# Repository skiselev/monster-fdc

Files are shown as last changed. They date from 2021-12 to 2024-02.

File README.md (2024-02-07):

# Monster Floppy Disk Controller (Monster FDC)
ISA floppy disk controller card that supports up to 8 floppy drives

## Introduction
Monster FDC is an ISA floppy disk controller card that features two FDCs. Each FDC supports up to four floppy drives. IRQ and DMA channel are configurable for the secondary FDC, and they are hardwired to IRQ6 and DMA2 for the primary FDC. The card also includes a serial port (UART) with configurable I/O address and IRQ.

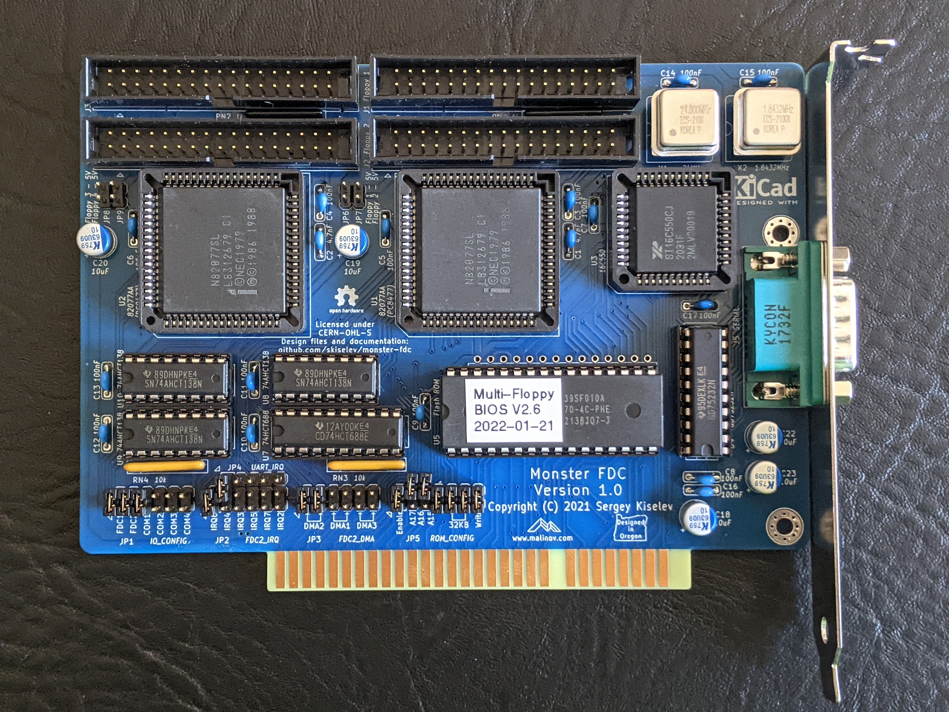
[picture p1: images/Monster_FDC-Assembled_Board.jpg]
Monster FDC Assembled Board
 

## User Manuals

* Refer to [Assembly Instructions](Assembly_Instructions.md) for the controller board building instructions
* Refer to [User Manual](User_Manual.md) for configuration, installation, and using the controller board in the computer

## Hardware Documentation

### Schematic and PCB Layout

[Schematic - Version 1.0](KiCad/isa_monster_fdc-Schematic-1.0.pdf)

[PCB Layout - Version 1.0](KiCad/isa_monster_fdc-Board-1.0.pdf)

### Bill of Materials

#### Version 1.0

[Monster FDC project on Mouser.com](https://www.mouser.com/ProjectManager/ProjectDetail.aspx?AccessID=8ae2858f5a) - View and order all components except of the PCB and the FDC ICs. Note that this BOM includes multiple alternatives for some parts (for example, for 2x17 pin floppy disk connector). Make sure to refer to the BOM below to order the right number of components.

Monster FDC project on Tindie: [Complete Board](https://www.tindie.com/products/weird/monster-fdc/); [Monster FDC PCB](https://www.tindie.com/products/weird/monster-fdc-pcb-only/).

Component type     | Reference | Description                                 | Quantity | Possible sources and notes 
------------------ | --------- | ------------------------------------------- | -------- | --------------------------
PCB                |           | Monster PCB - Version 1.0                   | 1        | Buy from my Tindie store: [Monster FDC PCB](https://www.tindie.com/products/weird/monster-fdc-pcb-only/), or order from a PCB manufacturer of your choice using provided Gerber or KiCad files. It is recommended to use hard gold plating on the card edge connector. ENIG finish might work, but it is not as reliable. Definitely **DO NOT** use HASL finish on card edge connector.
Integrated Circuit | U1, U2    | Intel 82077AA FDC, 68 pin PLCC              | 2        | eBay; Possible replacements: National Semiconductor PC8477BV-1 or PC8477AV-1, Intel 82077SL, Intel 82077AA with various suffixes
Integrated Circuit | U3        | 16C550 UART, 44 pin PLCC                    | 1        | Mouser [701-ST16C550CJ44-F](https://www.mouser.com/ProductDetail/701-ST16C550CJ44-F)
Integrated Circuit | U4        | GD75232N RS-232 Transceivers, 20 pin DIP    | 1        | Mouser [595-GD75232N](https://www.mouser.com/ProductDetail/595-GD75232N)
Integrated Circuit | U5        | SST39SF010A - 128 KiB Flash ROM, 32 pin DIP | 1*       | Mouser [804-39SF010A7CPHE](https://www.mouser.com/ProductDetail/804-39SF010A7CPHE); Possible replacements: 128 KiB, 256 KiB, or 512 KiB 5V only Flash ROMs from other vendors. Note: Install either U5 or U6. It is recommended to install U5
Integrated Circuit | U6        | 28C256 32 KiB or 28C64 8 KiB EEPROM, 28 pin DIP | 1*   | Mouser [556-AT28C25615PU](https://www.mouser.com/ProductDetail/556-AT28C25615PU), [556-AT28C64B15PU](https://www.mouser.com/ProductDetail/556-AT28C64B15PU). Note: Install either U5 or U6. It is recommended to install U5
Integrated Circuit | U7        | CD74HCT688E Magnitude Comparator, 20 pin DIP | 1       | Mouser [595-CD74HCT688E](https://www.mouser.com/ProductDetail/595-CD74HCT688E)
Integrated Circuit | U8 - U10  | SN74AHCT138N 3-to-8 Decoder, 16 pin DIP     | 3        | Mouser [595-SN74AHCT138N](https://www.mouser.com/ProductDetail/595-SN74AHCT138N)
Crystal Oscillator | X1        | 24 MHz, 4 pin DIP, Half Can                 | 1        | Mouser [520-TCH2400](https://www.mouser.com/ProductDetail/520-TCH2400)
Crystal Oscillator | X2        | 1.8432 MHz, 4 pin DIP, Half Can             | 1        | Mouser [520-TCH184-X](https://www.mouser.com/ProductDetail/520-TCH184-X)
Connector          | J1 - J4   | 2x17 pin shrouded header, 2.54 mm pitch, vertical | 4  | Mouser [517-30334-6002](https://www.mouser.com/ProductDetail/517-30334-6002)
Connector          | J5        | DE-9 D-Sub connector, male, right angle     | 1        | Mouser [806-K22X-E9P-N-99](https://www.mouser.com/ProductDetail/806-K22X-E9P-N-99)
Pin Header         | JP1 - JP3 | 2x6 pin header, 2.54 mm pitch, vertical     | 3        | Mouser [649-67996-112HLF](https://www.mouser.com/ProductDetail/649-67996-112HLF)
Pin Header         | JP4       | 1x5 pin header, 2.54 mm pitch, vertical     | 1        | Mouser [649-68000-205HLF](https://www.mouser.com/ProductDetail/649-68000-205HLF)
Pin Header         | JP5       | 2x7 pin header, 2.54 mm pitch, vertical     | 1        | Mouser [649-67996-114HLF](https://www.mouser.com/ProductDetail/649-67996-114HLF)
Pin Header         | JP6 - JP9 | 2x2 pin header, 2.54 mm pitch, vertical     | 2*       | Mouser [649-67996-104HLF](https://www.mouser.com/ProductDetail/649-67996-104HLF). Note: Do not install unless using PS/2 floppy drives that are powered by pin 3
Capacitor          | C1, C2    | 4.7 nF, 50V, MLCC, 5 mm pitch               | 2*       | Mouser [810-FG28X7R1H472KNT0](https://www.mouser.com/ProductDetail/810-FG28X7R1H472KNT0). Note: Optional, only required when using Intel 82077AA FDC
Capacitor          | C3 - C17  | 100 nF, 50V, MLCC, 5 mm pitch               | 15       | Mouser [810-FG28X7R1H104KNT6](https://www.mouser.com/ProductDetail/810-FG28X7R1H104KNT6)
Capacitor          | C18 - C23 | 10 uF, 63V, Organic Polymer, 6.3 mm diameter, 2.5 mm pitch| 5 | Mouser [80-A759EA106M1JAAE60](https://www.mouser.com/ProductDetail/80-A759EA106M1JAAE60)
Resistor Array     | RN1, RN2  | 1 kohm, bussed, 6 pin SIP                   | 2        | Mouser [652-4606X-1LF-1K](https://www.mouser.com/ProductDetail/652-4606X-1LF-1K)
Resistor Array     | RN3, RN4  | 10 kohm, bussed, 6 pin SIP                  | 2        | Mouser [652-4606X-1LF-10K](https://www.mouser.com/ProductDetail/652-4606X-1LF-10K)
IC Socket          | U1, U2    | 68 pin PLCC, through hole                   | 2        | Mouser [517-8468-11B1-RK-TP](https://www.mouser.com/ProductDetail/517-8468-11B1-RK-TP)
IC Socket          | U3        | 44 pin PLCC, through hole                   | 1        | Mouser [517-8444-11B1-RK-TP](https://www.mouser.com/ProductDetail/517-8444-11B1-RK-TP)
IC Socket          | U4, U7    | 20 pin DIP                                  | 2        | Mouser [649-DILB20P-223TLF](https://www.mouser.com/ProductDetail/649-DILB20P-223TLF)
IC Socket          | U5        | 32 pin DIP                                  | 1*       | Mouser [649-DILB32P223TLF](https://www.mouser.com/ProductDetail/649-DILB32P223TLF). Note: Install either U5 or U6. It is recommended to install U5
IC Socket          | U6        | 28 pin DIP                                  | 1*       | Mouser [649-DILB28P223TLF](https://www.mouser.com/ProductDetail/649-DILB28P223TLF). Note: Install either U5 or U6. It is recommended to install U5
IC Socket          | U8 - U10  | 16 pin DIP                                  | 1        | Mouser [649-DILB16P-223TLF](https://www.mouser.com/ProductDetail/649-DILB16P-223TLF)
Oscillator Socket  | X1, X2    | 4 pin DIP, Half Can                         | 2        | Mouser [535-1108800](https://www.mouser.com/ProductDetail/535-1108800)
Jumper             | JP1 - JP5 | Shunt, 2 pin 2.54 mm pitch                  | 13       | Mouser [806-SX1100-B](https://www.mouser.com/ProductDetail/806-SX1100-B)
Computer Bracket   |           | Keystone Electronics 9200-1 Bracket with DE-9 cut-out | 1 | Mouser [534-9200-1](https://www.mouser.com/ProductDetail/534-9200-1), or a [3D printed bracket](https://www.thingiverse.com/thing:6473572). Note: Use when serial port components are populated
Screw              |           | 4-40 Hex screw for D-Sub Connector          | 2        | Mouser [806-JSX-1000](https://www.mouser.com/ProductDetail/806-JSX-1000). Note: Use when serial port components are populated
Computer Bracket   |           | Keystone Electronics 9202 ISA Bracket       | 1        | Mouser [534-9202](https://www.mouser.com/ProductDetail/534-9202). Note: Use when serial port components are **not** populated
Screw              |           | 4-40 / 1/4" screw (for attaching ISA Bracket to the board) | 2 | Mouser [534-9900](https://www.mouser.com/ProductDetail/534-9900). Note: Use when serial port components are **not** populated

#### Devices and Functionality

The card can be built with some or all of the following devices and functionality:
* Primary FDC controller
* Secondary FDC controller
* Serial port / UART
* BIOS extension ROM (aka boot ROM)

The table below provides the list of components that are required for each one of the devices

Device/Functionality     | Components
-------------------------|------------------------------------------------------------------------------------------------
Primary FDC Controller   | U1, U8, U9, X1, J1, J2, JP1, JP6**, JP7**, C1*, C3, C5, C11, C12, C14, C19, RN1, RN4
Secondary FDC Controller | U2, U8, U10, X1, J3, J4, JP1, JP2, JP3, JP8**, JP9**, C2*, C4, C6, C11, C13, C14, C20, RN2, RN4
Serial port / UART       | U3, U4, U8, U9, X2, J5, JP1, JP2, JP4, C7, C8, C11, C12, C15, C16, C17, C22, C23, RN4
BIOS extension ROM       | U5***, U6***, U7, JP5, RN3, C9, C10
Shared components        | C18

Notes:
* \* - only required for Intel 82077AA FDCs
* \** - only required when using IBM PS/2 floppy drives that are powered by 5V on pin 3
* \*** - install either U5 (recommended) or U6
* Use Keystone Electronics 9200-1 Bracket when populating serial port components. This bracket attaches to the serial port DE-9 connector
* Use Keystone Electronics 9202 ISA Bracket when not populating serial port components. This bracket attaches to the board with a couple of 4-40 screws

#### Possible Component Replacements

* U1, U2 - Intel 82077AA FDC
  * National Semiconductor PC8477BV-1 - recommended
  * Intel N82077SL - recommended
  * Intel N82077AA - recommended, no tape support
  * Intel N82077AA-1 - tape support, FM broken
  * Intel N82077AA-5 - doesn't support 1 Mbps rate / ED disks
  * National Semiconductor PC8477AV-1 - an older version of PC8277BV-1
* U3 - 16C550 UART
  * Most 16450/16550A type UARTs in PLCC-44 package supporting 5V operation
  * 16C550 and 16550A type UARTs from other vendors - Texas Instruments, National Semiconductor, MaxLinear, NXP Semiconductors
  * 16C650, 16C750, 16C850 type UARTs (longer FIFO)
  * 16C450, 16450, 16550 type UARTs without FIFO
* U4 - GD75232N RS-232 Transceivers 
  * Texas Instruments SN75185N, SN75C185
* U5 - 128 KiB Flash ROM 
  * Most 128 KiB Flash ROM ICs in DIP-32 package supporting 5V-only operation
  * Microchip/SST SST39SF010A, SST39SF020, SST39SF040
  * AMD Am29F010, Am29F020
  * Winbond W29EE011
  * Atmel AT29C010A
  * Greenliant/SST SST29EE010/GLS29EE010
  * 256 KiB, and 512 KiB Flash ROM ICs in DIP-32 package supporting 5V-only operation can be used as well, but are not currently supported by the built-in configuration utility and xiflash utility
  * Note that only first 32 KiB will be used regardless of the ROM capacity
* U6 - 32 KiB or 8 KiB EEPROM
  * Atmel AT28C256, AT28C64B
* U7 - CD74HCT688E Magnitude Comparator
  * 74HCT688
  * 74LS668, 74F521
* U8 - U10 - SN74AHCT138N 3-to-8 Decoder
  * 74AHCT138
  * 74HCT138
  * 74ALS138, 74F138, 74LS138
* X1
  * Any 24 MHz half can 5V oscillators
* X2
  * Any 1.8432 MHz half can 5V oscillators

## Release Notes

### Changes

* Version 1.0
  * Initial version

### Known Issues

None, so far

## Red Tape

### Licensing

Monster FDC is an open source hardware project certified by [Open Source Hardware Association](https://www.oshwa.org/), certification UID is [US002072](https://certification.oshwa.org/us002072.html). The hardware design itself, including schematic and PCB layout design files are licensed under the strongly-reciprocal variant of [CERN Open Hardware Licence version 2](license-cern_ohl_s_v2.txt). The [Multi-Flopppy BIOS](https://github.com/skiselev/floppy_bios) code is licensed under [GNU General Public License v3](license-gpl-3.0.txt). Documentation, including this file, is licensed under the [Creative Commons Attribution-ShareAlike 4.0 International License](license-cc-by-sa-4.0.txt).

CERN-OHL-2.0-S, GPL-3.0, CC-BY-SA-4.0

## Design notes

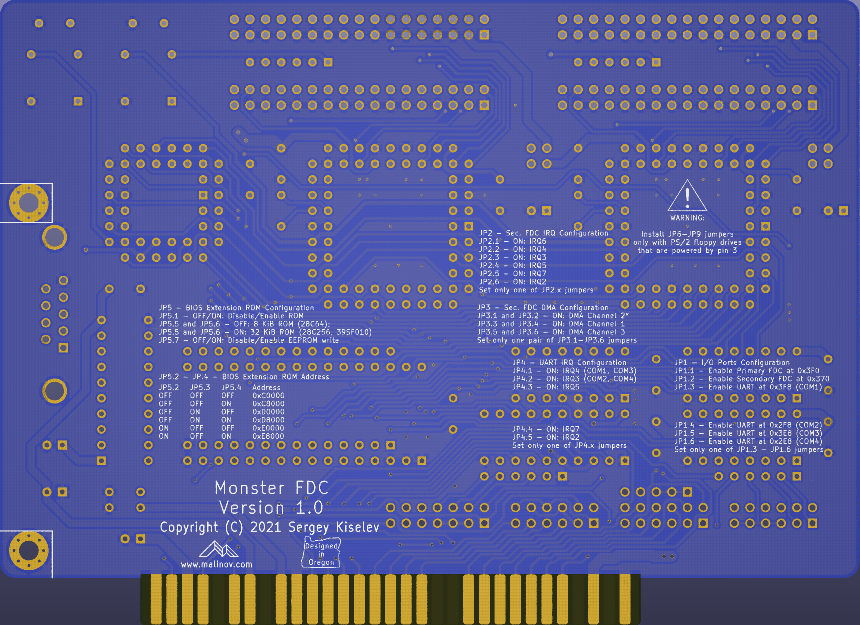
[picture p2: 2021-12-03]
images/isa_monster_fdc-bottom.png

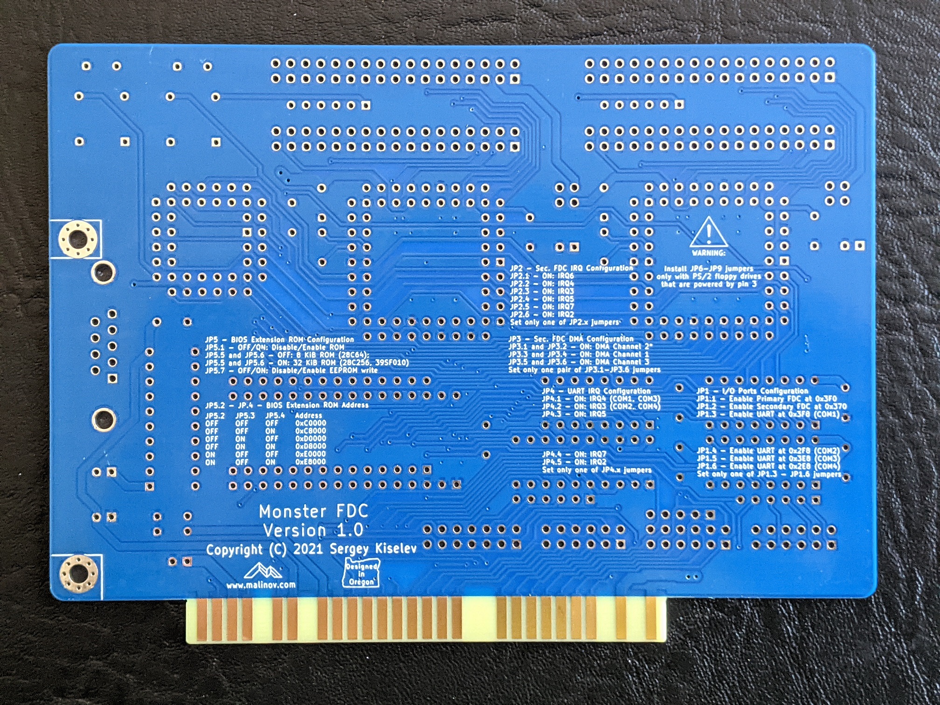
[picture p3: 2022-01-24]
images/Monster_FDC-PCB_Bottom.jpg

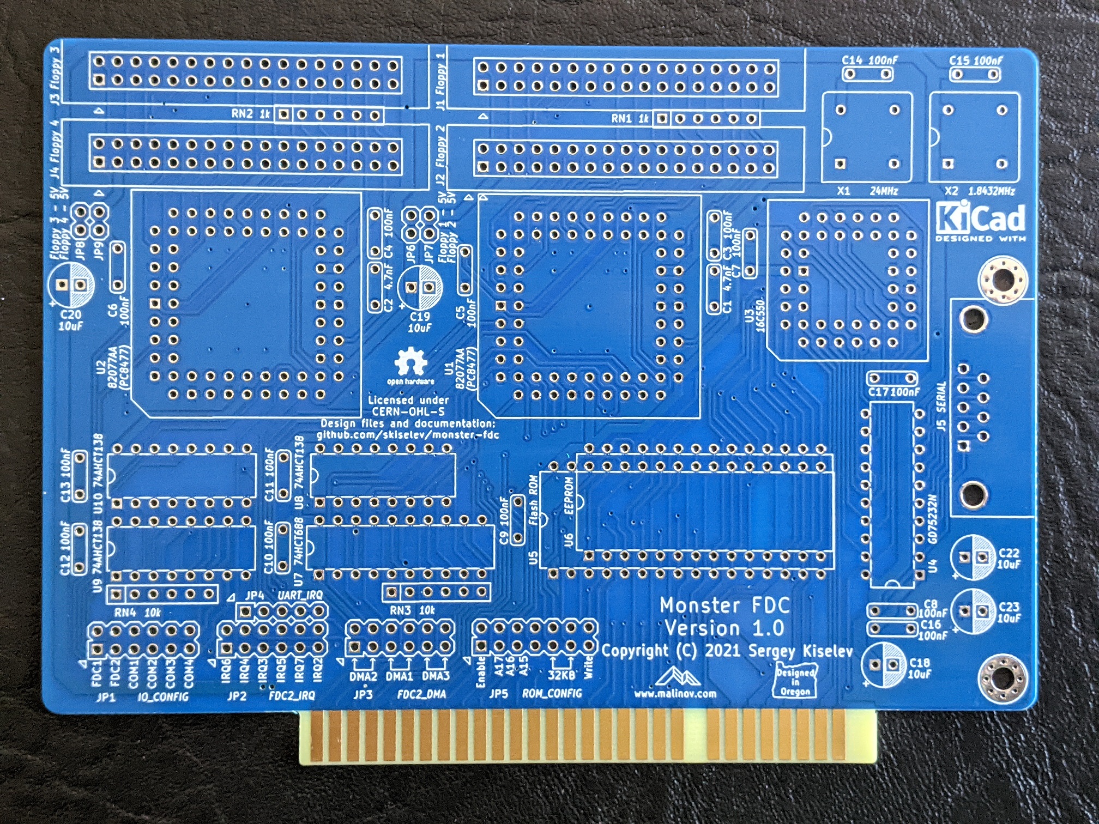
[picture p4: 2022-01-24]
images/Monster_FDC-PCB_Top.jpg

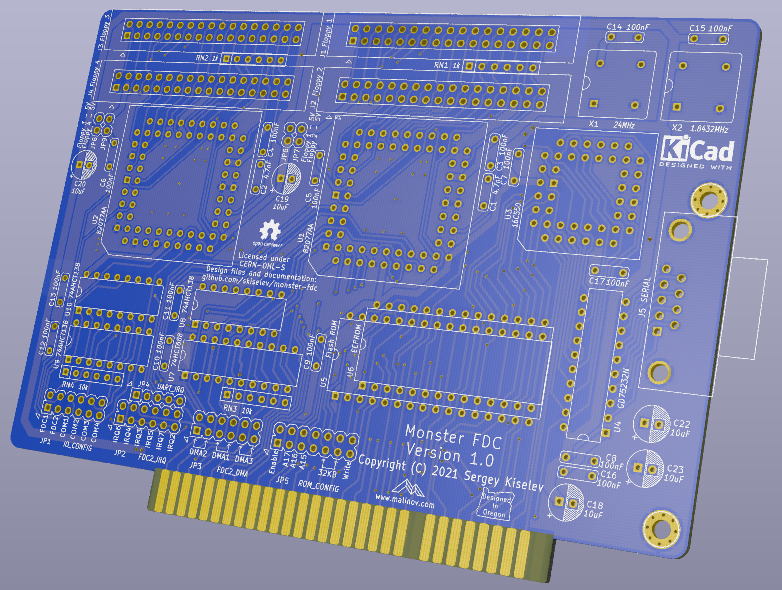
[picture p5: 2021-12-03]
images/isa_monster_fdc.png

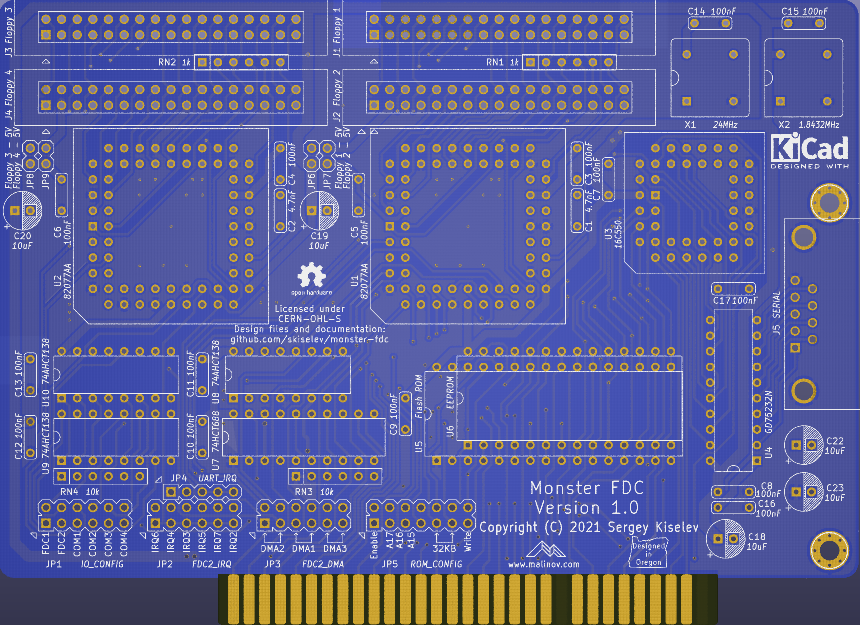
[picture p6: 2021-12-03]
images/isa_monster_fdc-top.png

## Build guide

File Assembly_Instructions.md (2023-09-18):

# Monster FDC - Assembly Instructions

## Prerequisites

### Tools, Equipment, and Supplies

* Soldering iron with a fine tip. Temperature controlled soldering station is recommended
* Small side cutters for cutting components' leads
* Universal programmer capable of programming SST39F010A Flash ROM ICs. For example, MiniPro TL866CS or MiniPro TL866A (optional, Flash ROM can be programmed in-system)
* Multimeter with frequency measurement, an oscilloscope, or a logic analyzer can be beneficial for troubleshooting
* Desk lamp, magnifying glass
* Solder suitable for soldering electronics. For example: rosin core Sn63/Pb37, Sn60/Pb40, or a lead-free solder such as Sn96.5/Ag3.0/Cu0.5 (sometimes referred to as SAC305)
* Solder wick for removing excess of solder
* 99% Isopropyl Alcohol for removing the excess of flux after soldering
* Lint free wipes, used toothbrush, cotton swabs for cleaning the PCB before and after soldering

### Parts

The up to date list of parts provided in the [Bill of Materials](README.md#bill-of-materials) section of the [README.md](README.md) file.
It also provides the recommended sources for the parts.
Additionally, refer to the [Devices and Functionality](README.md#devices-and-functionality)
and [Possible Component Relacement](README.md#possible-component-replacements) sections for alternative and optional components.

Prior to assembling the board, you might want to program the Flash ROM with [Multi-Floppy BIOS extension](https://github.com/skiselev/floppy_bios).
The [floppy_bios.bin](https://github.com/skiselev/floppy_bios/blob/master/floppy_bios.bin) file is the compiled binary ROM image.
Alternatively, you can flash the Flash ROM in system using [xiflash](https://github.com/skiselev/xiflash) utility.

## Assembly Steps

### 1. Gather supplies and parts

* Check that you have all the equipment and parts listed in the [Prerequisites](#prerequisites) section above
* Organize your workspace. If available, use ESD-safe surface and ESD strap when working on this project

### 2. Solder the components

Solder the components going from lower profile components to higher profile components, from smaller components to larger. Here is the recommended order:

* Solder RN1 - RN4 resistor arrays
  * Make sure that resistor arrays are oriented correctly. The first pin of the resistor array is marked with a printed dot, and the first pad on the board has a square shape
* Solder C1 - C2 4.7 nF capacitors
  * These capacitors are optional, and only required for Intel 82077AA FDCs (with any numeric suffix). No need to solder them if using National Semiconductor PC8744 or Intel 82077SL FDCs
    * Note: The board will function correctly if these capacitors are soldered regardless of FDC type
  * These are non-polarized ceramic capacitors, so they can be oriented either way
  * Trim the leads using cutters
* Solder C3 - C17 100 nF capacitors
  * These are non-polarized ceramic capacitors, so they can be oriented either way
  * Trim the leads using cutters
* Solder C18 - C23 10 uF capacitors
  * These are polarized capacitors and must be oriented correctly. The negative (-) side usually marked with paint, and the negative (-) lead is shorter than the positive (+) one
  * Trim the leads using cutters
* Solder X1 - X2 oscillator sockets
  * Make sure that sockets are oriented correctly. The notch on the socket should match with the notch on the board's silkscreen
  * The oscillators can be soldered directly to the board without sockets. This will reduce cost, improve reliability, but make it more difficult to repair the board
* Solder U4 - U10 DIP sockets
  * Make sure that sockets are oriented correctly. The notch on the socket should match with the notch on the board's silkscreen
  * It is recommended to solder two opposite pins first (e.g., pin 1 and pin 9 for a DIP-16 socket), and then verify that the socket is oriented correctly and sits flush on the board. Resolder if needed.
  * Either U5 (DIP-32) socket or U6 (DIP-28) socket should be installed. The choice depends on whether Flash ROM or EEPROM will be used with the board.
  * U4, and U7 - U10 ICs can be soldered directly to the board without sockets. This will reduce cost, improve reliability, but make it more difficult to repair the board
  * It is recommended that U5 or U6 will be socketed, so, if needed, they can be easily extracted for reprogramming
* Solder U1 - U3 PLCC sockets
  * Make sure that sockets are oriented correctly. The cut corner on the socket should match the cut corner on the board's silkscreen
* Solder JP1 - JP9 headers
  * It is recommended to solder one pin first, verify that the header is oriented upright and sits flush with the board, and then solder the rest of the pins
  * Headers JP6 - JP9 should be only installed if the board will be used with IBM PS/2 floppy drives that are powered by pin 3 on the floppy drive connector
* Solder J1 - J4 connectors
  * These connectors need to be oriented correctly. The cutout in the middle of the connector shroud should point down toward the ISA connector
* Finally, solder the J5 connector

### 3. Check your soldering work

* Make sure all pins of all components are soldered properly
* If desired, clean the flux using isopropyl alcohol, cotton swabs. You might want to scrub the board lightly with a used toothbrush to remove the flux

### 4. Insert the integrated circuits to the sockets

* Prior to inserting DIP integrated circuits to the sockets board, bend their leads slightly, so they point 90 degrees downward. Put the IC on the side and gently push it down to bend the leads. Repeat on the other side of the IC
* Double check that you're placing the integrated circuit in the right socket, check the IC orientation. The index notch on the IC should match the notch on the socket and the drawing on the PCB's silkscreen
* To insert the FDC and UART integrated circuits in PLCC packages, place the integrated circuit on the top of the socket, double check the orientation of the integrated circuit, and firmly push the package down. It should click into the socket
* Insert X1 and X2 oscillators into the sockets
* Double check that all ICs and oscillators are oriented correctly:
  * Orient the board with the ISA connector pointing down or toward you
  * U1 - U4 ICs (all PLCC and GD75232 IC in DIP-20 package) should have the print/marking on the packages read bottom to top
  * U5 - U10 ICs and X1, X2 oscillators should have the print/marking on the packages read left to right
  * Note that the print/marking on C18 - C23 capacitors will appear upside down

### 5. Place jumpers on JP1 - JP5 jumper blocks

Refer to the [User Manual](User_Manual.md) for the jumpers' description

**Important**: Do not place JP6-JP9 jumpers unless you're absolutely sure you are using IBM PS/2 floppy drives that are powered by pin 3 of the floppy connector

### 6. Test the Monster FDC controller card

* Plug the card into an ISA slot of an IBM PC/XT or IBM AT compatible computer
* Connect floppy drives' cables to the card's J1 - J4 connectors
* If desired, connect a serial device to the serial port J5 connector. It is possible to use a loopback plug, or a serial mouse to test the serial port
* Power on the system
  * Assuming that the Flash ROM / EEPROM is installed on the card, and it is programmed with the Multi-Floppy BIOS extension,
you should see Multi-Floppy BIOS configuration print-out during the POST (Power-on self test)
  * Once the POST post is complete, you should also see a Multi-Floppy BIOS extension configuration utility prompt. Press **F2** to enter the configuration utility
  * Configure the card according to the drive types you have in your system. Refer to the [User Manual](User_Manual.md) for the configuration utility usage information
* Boot into the OS using either a bootable floppy disk, or HDD/SSD
* Test that FDCs and floppy drives are working by copying files from one floppy drive to another, or from HDD to the floppy drive and vice versa
* Test that the serial port is working using either a diagnostic utility that supports a serial loopback, such as CheckIt, or if using a serial mouse, load mouse driver and make sure the mouse is working

If the Flash ROM was not programmed prior to installing the controller card in the computer, it can be programmed in system, using [xiflash](https://github.com/skiselev/xiflash) utility.
In this case download or copy the xiflash.exe file and floppy_bios.bin into your computer, boot to the DOS prompt and issue the following command:
```
xiflash -i floppy~1.bin -a c800 -p
```
and **reboot the computer**. Make sure to use the correct Multi-Floppy BIOS extension file name (floppy~1.bin in the example above), and the correct BIOS extension ROM address (segment - c800 in the example above). It should match the address set by JP5.2-JP4 jumpers
Once the computer reboots, follow the steps described above to configure and test the card.

Note: In order to save configuration and to re-program the Flash ROM in system, the ROM needs to be enabled (JP5.1 set) and write access allowed (JP5.7 set). It is possible to remove the latter once the card is configured to prevent accidental configuration change or Flash ROM re-programming/corruption.

__Congratulations! Enjoy your Monster FDC Controller Card!__

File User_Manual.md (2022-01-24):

# Monster FDC - User Manual

## Installation Procedure Outline

* Prior to installing the Monster FDC controller card, configure the controller jumpers as described in the [Configuration Jumpers](#configuration-jumpers) section below
* Install the card in your computer and connect floppy drives
* Power on the computer and launch the built-in Multi-Floppy BIOS configuration utility to configure controllers and floppy drives
* If needed, modify the OS configuration

## Configuration Jumpers

Monster FDC controller card is configured using jumpers. There are four blocks of jumpers that configure controller resources and two optional blocks that are used to connect +5V power supply to pin 3 of floppy disk connectors. Certain IBM PS/2 floppy drives are powered using this pin.

When configuring resources - I/O addresses, IRQs, DMA channels, and memory addresses for the BIOS extension ROM, make sure that resources are available and are not used
by other extension cards or built-in devices on the motherboard.

### JP1 - I/O Configuration

JP1 jumper block enables the primary and the secondary floppy disk controllers (FDCs), and enables and sets I/O address for the serial port (UART).

Jumper | Closed                                          | Open
-------|-------------------------------------------------|-------------------------------------
JP1.1  | Enable primary FDC (I/O address: 0x3F0)         | Disable primary FDC
JP1.2  | Enable secondary FDC (I/O address: 0x370)       | Disable secondary FDC
JP1.3  | Enable serial port at COM1 (I/O address: 0x3F8) | Do not configure serial port at COM1
JP1.4  | Enable serial port at COM2 (I/O address: 0x2F8) | Do not configure serial port at COM2
JP1.5  | Enable serial port at COM3 (I/O address: 0x3E8) | Do not configure serial port at COM3
JP1.6  | Enable serial port at COM4 (I/O address: 0x2E8) | Do not configure serial port at COM4

**Note:** Set only one of JP1.3 - JP1.6 jumpers, or no jumpers at all to disable serial port functionality

### JP2 - Secondary FDC IRQ Configuration

JP2 configures the hardware interrupt request (IRQ) for the secondary FDC. The primary FDC is hardwired to use IRQ6

Jumper | Closed                              | Open
-------|-------------------------------------|--------------------------------------
JP2.1  | Use IRQ6 for the secondary FDC      | Do not use IRQ6 for the secondary FDC
JP2.2  | Use IRQ4 for the secondary FDC      | Do not use IRQ4 for the secondary FDC
JP2.3  | Use IRQ3 for the secondary FDC      | Do not use IRQ3 for the secondary FDC
JP2.4  | Use IRQ5 for the secondary FDC      | Do not use IRQ5 for the secondary FDC
JP2.5  | Use IRQ7 for the secondary FDC      | Do not use IRQ7 for the secondary FDC
JP2.6  | Use IRQ2/IRQ9 for the secondary FDC | Do not use IRQ2/IRQ9 for the secondary FDC

**Notes:**
* Set only one of JP2.1 - JP2.6 jumpers

### JP3 - Secondary FDC DMA Configuration

JP3 configures the DMA channel (DRQ and DACK) for the secondary FDC. The primary FDC is hardwired to use DMA channel 2

Jumpers         | Closed                                  | Open
----------------|-----------------------------------------|-----------------------------------------------
JP3.1 and JP3.2 | Use DMA channel 2 for the secondary FDC | Do not use DMA channel 2 for the secondary FDC
JP3.3 and JP3.4 | Use DMA channel 1 for the secondary FDC | Do not use DMA channel 1 for the secondary FDC
JP3.5 and JP3.6 | Use DMA channel 3 for the secondary FDC | Do not use DMA channel 3 for the secondary FDC

**Notes:**
* Set only one pair of jumpers: either JP3.1 and JP3.2, JP3.3 and JP3.4, or JP3.5 and JP3.6

### JP4 - Serial Port IRQ Configuration

JP4 configures the hardware interrupt request (IRQ) for the serial port (UART). Note that JP3 shares a row with JP2 that is used to set IRQ for the secondary FDC.
This ensures that an IRQ is allocated to either the serial port or to the secondary FDC, but not to both of them at the same time.

Jumper | Closed                              | Open
-------|-------------------------------------|--------------------------------------
JP4.1  | Use IRQ4 for the serial port (COM1) | Do not use IRQ4 for the serial port
JP4.2  | Use IRQ3 for the serial port (COM2) | Do not use IRQ3 for the serial port
JP4.3  | Use IRQ5 for the serial port        | Do not use IRQ5 for the serial port
JP4.4  | Use IRQ7 for the serial port        | Do not use IRQ7 for the serial port
JP4.5  | Use IRQ2/IRQ9 for the serial port   | Do not use IRQ2/IRQ9 for the serial port

**Note:** Set only one of JP4.1 - JP4.5 jumpers

### JP5 - BIOS Extension ROM Configuration

JP5 enables BIOS extension ROM, enables or disables write access to the BIOS extension ROM, sets the ROM size and memory address

Jumper          | Closed                                 | Open
----------------|----------------------------------------|--------------------------------------
JP5.1           | Enable BIOS extension ROM              | Disable BIOS extension ROM
JP5.2 - JP5.4   | Set BIOS extension ROM address         | See table below
JP5.5 and JP5.6 | Set 32 KiB ROM size (39SF010A, 28C256) | Set 8 KiB ROM size (28C64)
JP5.7           | Enable BIOS extension ROM writes       | Disable BIOS extension ROM writes

#### JP5.2 - JP5.4 - Configure BIOS Extension ROM Address

JP5.2  | JP5.3  | JP5.4  | ROM Address
-------|--------|--------|-----------------------------------------------------------------------
Open   | Open   | Open   | 0xC0000 (**Note:** This address will conflict with EGA/VGA Video BIOS)
Open   | Open   | Closed | 0xC8000
Open   | Closed | Open   | 0xD0000
Open   | Closed | Closed | 0xD8000
Closed | Open   | Open   | 0xE0000
Closed | Open   | Closed | 0xE8000

### JP6 - JP9 - Enable +5V on Pin 3 of Floppy Drive Connector

JP6 - JP9 are used to connect +5V power supply voltage to pin 3 of floppy drive connectors. Certain IBM PS/2 floppy drives are powered using this pin.

**Warning:** Do not connect JP6-JP7 jumpers unless you are certain that your floppy drive is powered using pin 3. Such drives normally do not have separate power connector.
If in doubt, check that pin 3 is not connected to the ground on the floppy drive. Setting this jumper with the floppy drive that grounds pin 3 will result in a short circuit
and possible damage to the floppy disk controller, floppy drive, motherboard, or power supply

Jumper | Closed                                          | Open
-------|-------------------------------------------------|--------------------------------------------------
JP6    | Connect +5V to pin 3 of J1 / Floppy 1 connector | Keep pin 3 of J1 / Floppy 1 connector unconnected
JP7    | Connect +5V to pin 3 of J2 / Floppy 2 connector | Keep pin 3 of J2 / Floppy 2 connector unconnected
JP8    | Connect +5V to pin 3 of J3 / Floppy 3 connector | Keep pin 3 of J3 / Floppy 3 connector unconnected
JP9    | Connect +5V to pin 3 of J4 / Floppy 4 connector | Keep pin 3 of J4 / Floppy 4 connector unconnected

## Multi-Floppy BIOS Extension ROM

The Monster FDC card uses [Multi-Floppy BIOS Extension ROM](https://github.com/skiselev/floppy_bios) to provide support for the floppy drive formats that might otherwise not
be supported by the System BIOS and to support more floppy drives that the System BIOS supports.

### Multi-Floppy BIOS Configuration Utility

The Multi-Floppy BIOS Extension ROM features a built-in configuration utility, that is used to configure floppy drive types connected to the controller card, and to set up the secondary FDC resources (IRQ, DMA channel). Press **F2** button during BIOS POST to access the configuration utility. The configuration utility has a simple command line interface. The configuration commands are executed by pressing the corresponding command keys (just the key, no need to type **Enter**). While at the command prompt, use **h** command to list available commands. Commands that require parameters, display appropriate prompts. When prompted, enter the required parameter, or press **ESC** key to exit to the main menu.

#### Enabling / Disabling Secondary FDC

Use **e** command to enable the secondary FDC. This command will prompt for the IRQ and the DMA channel numbers. If the secondary FDC is already enabled, it can be used to change IRQ and DMA settings.

Use **d** command to disable the secondary FDC. Note that disabling the secondary FDC will delete the configuration for all drives that are currently configured on the secondary FDC.

#### Adding / Deleting Drives

Use **a** command to add (configure) a floppy drive:
* If the secondary FDC is enabled, this command will prompt for the FDC the drive is connected to (primary or secondary)
* Next it will prompt for the physical drive number (0-3)
  * For the primary FDC:
    * Drive 0 is the drive at the far end of the cable (after the "twist") connected to J1 / Floppy 1 connector
    * Drive 1 is the drive in the middle of the cable (before the "twist") connected to J1 / Floppy 1 connector
    * Drive 2 is the drive at the far end of the cable (after the "twist") connected to J2 / Floppy 2 connector
    * Drive 3 is the drive in the middle of the cable (before the "twist") connected to J2 / Floppy 2 connector
  * For the secondary FDC:
    * Drive 0 is the drive at the far end of the cable (after the "twist") connected to J3 / Floppy 3 connector
    * Drive 1 is the drive in the middle of the cable (before the "twist") connected to J3 / Floppy 3 connector
    * Drive 2 is the drive at the far end of the cable (after the "twist") connected to J4 / Floppy 4 connector
    * Drive 3 is the drive in the middle of the cable (before the "twist") connected to J4 / Floppy 4 connector
* Then, it will prompt for the logical drive number.
  * The logical drive number corresponds to the drive number from software (BIOS calls) perspective
  * It roughtly corresponds to DOS drive letters - drive 0 = A:, drive 1 = B:, drives' letter assignments after drive B: depend on the DOS version. Newer DOS versions, use C: and following letters for hard drive partitions, and place any remaining floppy drives after hard drive letters. For example, on systems with four floppy drives and two HDD partitions, the drives will be assigned as following: A: - floppy drive 0, B: - floppy drive 1, C: - HDD partition 1, D: - HDD partition 2, E: - floppy drive 2, F: - floppy drive 3
  * The range of logical drive numbers depends on the number of already configured drives
    * Entering a number at the end of the range will add a drive to the end of the list
    * Entering a number in the middle will "insert" the drive, incrementing the logical drive numbers for the following drives
* Finally the configuration utility will prompt for the drive type

Use **d** command to delete a floppy drive. Note that deleting a drive will decrement the logical drive numbers for the following drives (if any).

#### Configuring Initial Program Loader (IPL) Method

Normally, at the end of Power-on Self Test (POST) the System BIOS calls INT 19h to boot the OS. The System BIOS has a default handler for INT 19h.
The functionality of the System BIOS handler depends on System / BIOS type. For example, IBM PC/XT and clones only support booting from floppy drives, and in certain cases will
not support boot from Multi-Floppy BIOS drives. IBM AT systems and clones will also attempt to boot from HDD. Some newer BIOSes have an option to setup the boot sequence.
In addition, other extension cards, for example SCSI / HDD controllers and Network Interface Cards might install their own INT 19h handler to support boot from these devices.

The Multi-Floppy BIOS support two IPL methods:
1. Built-in Multi-Floppy BIOS IPL. This method attempts to boot from the first (logical number 0) floppy drive. It should be used in IBM PC/XT and clone systems, or otherwise if boot from the floppy drive is desirable, but not working with System BIOS / HDD BIOS extensions.
2. System BIOS IPL. This method uses the default System BIOS (or an HDD BIOS extension) IPL. It should be used in IBM AT compatible systems

Use **i** command to configure the IPL method.

#### Other Commands

* Use **p** command to print the current configuration
* Use **w** command to write the configuration to the flash ROM / EEPROM and reboot the system. Note that flash ROM / EEPROM needs to be writable - the JP5.7 jumper must be set, and on newer systems, the caching for the memory range where Multi-Floppy BIOS Extension ROM resides should be disabled
* Use **q** command to exit configuration utility without writing the configuration to the flash ROM / EEPROM
* Use **h** command to print help
* Use **ESC** button while running a command to exit to the main menu

## DOS Configuration

It appears that by default, MS-DOS (tested on MS-DOS 6.22) does not support more than 4 floppy drives. Use DRIVER.SYS in CONFIG.SYS to add more drives.

The syntax is:
```
DEVICE=C:\DOS\DRIVER.SYS /D:number /F:type /C
```

Where:
* **number** specifies the logical drive number as assigned in the Multi-Floppy BIOS configuration utilty
* **type** specifies the floppy drive type: 
  * 0 - Double-density 360K, 5 1/4-inch floppy disk drives, including 160K, 180K, and 320K formatted media sizes
  * 1 - High-density, 1.2M, 5 1/4-inch floppy disk drives.
  * 2 - Double-density, 720K, 3 1/2-inch floppy disk drives.
  * 7 - High-density, 1.44M, 3 1/2-inch floppy disk drives.
  * 9 - Extended-density, 2.88M, 3 1/2-inch floppy disk drives.
* **/C** is an optional parameter indicating that the floppy drive supports "disk change" detection. Normally 1.2 MB, 1.44 MB, and 2.88 MB drives support this

When configuring multiple floppy drives, several "DRIVER.SYS" lines can be added into CONFIG.SYS

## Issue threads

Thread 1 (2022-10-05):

EEPROM part number question

snhirsch, 2022-10-05:
The specified Flash ROM is not currently available, but I found an Intel 28F001 and SST PH29EE010 in my parts drawers.  Are either / both of these acceptable substitutes?

skiselev, 2022-10-05:
The SST PH29EE010 should work. Intel 28F001 is not a good choice, as it requires 12Vpp.
Please try it with SST PH29EE010, and report back :)

snhirsch, 2022-10-07:
Hi, Sergey.  I'm guessing you're too busy to respond.  Thanks anyway for your work on this device.  Since the second FDC is working at the hardware level I can use it with Imagedisk, so no big deal if BIOS support is lacking.  If I ever find a solution for the EEPROM image corruption I'll let you know.

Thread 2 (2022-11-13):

No drive working

wlpppaul, 2022-11-13:
Hello,

i get "Drive not ready" on all drives i try to connect. I tried different cables with a 1.44MB and a 1.2MB Drive.
When accessing a: or b: the correct drive responds and lights up. But only two anounce drive not ready after some seconds.

I tried in a P2 and a 386sx.

Do you have and idea what could be the reason?

Thank you :-)

skiselev, 2022-11-16:
A couple of things to check:
- Do you see the Multi-Floppy BIOS Extension messages/prompts when the system boots? If not, check that you have flashed that to the Flash ROM, and properly configured the ROM address
- Disable floppies in the system BIOS
- Disable the on board FDC if any (usually on P2 boards came with one)
- Of course, it could be a faulty FDC...  if nothing else helps, try swapping it with another FDC

BTW, I haven't tested Monster FDC on much newer systems (e.g. P2), and there might be some issues there...

skiselev, 2023-09-18:
No response or reproducer. Closing the issue. Feel free to reopen if you have more information

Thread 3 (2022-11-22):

Minimal hw configuration features?

AndersBNielsen, 2022-11-22:
The readme describes the board would work with just a single FDC + address decoding. Looks like an amazingly cheap alternative to buying a vintage FDC card.

Does that mean it would work with any drive the stock BIOS normally supports? (Without the bios extension)

Specifically I’m curious if I can get a 1.44Mb HD drive with an IBM XT 5160 (with 82 or ‘86 BIOS) - maybe just as a DD 720K drive? (Not sure what I can expect from the XT)

Basically, what can I expect from the minimal configuration with one FDC?

skiselev, 2023-05-31:
- The Monster FDC board will work with the system BIOS. In this case it would only support the first FDC
- System BIOS of IBM PC/XT and compatibles only supports disk up to 720 KB. You can use 3.5"/1.44MB drives, but only with 720 KB diskettes (tape the "density detect" hole, if you like to format a 1.44 MB diskette as 720 KB). These systems typically support up to 4 drives
- System BIOS of IBM AT and compatibles normally only supports 2 drives

If you're looking for a simpler FDC board, you could build or buy a board with only one FDC. For example my [ISA Floppy Disk and Serial Controller](http://www.malinov.com/Home/sergeys-projects/isa-fdc-and-uart), or derivatives, such as [Monotech DeluxeFloppy](https://monotech.fwscart.com/DeluxeFloppy_-_8-bit_ISA_Bootable_HD_Floppy_+_Serial/p6083514_19478745.aspx) or [TexElec Quad-Flop](https://texelec.com/product/quad-flop-four-port-isa-floppy-controller/).

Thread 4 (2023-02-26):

3rd Floppy setting itself as Drive C

mudmin, 2023-02-26:
Thanks for an awesome project.  I've confirmed this behavior with someone else who built these cards separately.  Our 3rd floppy drives always try to become the C drive meaning that we can't boot to our hard drive if we have more than 2 floppies in the system.

Is there anything that we can do to prevent this?  A particular DOS version?  DOS 6.22 doesn't seem to do the trick.

Although the documentation says **_It roughtly corresponds to DOS drive letters - drive 0 = A:, drive 1 = B:, drives' letter assignments after drive B: depend on the DOS version. Newer DOS versions, use C: and following letters for hard drive partitions, and place any remaining floppy drives after hard drive letters. For example, on systems with four floppy drives and two HDD partitions, the drives will be assigned as following: A: - floppy drive 0, B: - floppy drive 1, C: - HDD partition 1, D: - HDD partition 2, E: - floppy drive 2, F: - floppy drive 3_**  This isn't what's happening for either of us

skiselev, 2023-02-26:
Can you please provide more details?
What is the system/motherboard/BIOS?
What is the type of the hard drive controller?

Generally speaking, this should not be happening, as the floppy drives are enumerated separately from hard drives in the BIOS. Floppy are assigned numbers starting from 0, while hard drives are assigned numbers starting from 80h. So technically you could have 128 floppy drives, before their numbers will overlap with the hard drives.
During the boot, BIOS normally will try to boot from drive 0 - the first floppy drive, and drive 80h - the first hard drive. Drive letter assignment is a purely DOS think. BIOS doesn't know and doesn't care about them. So it is a bit puzzling to me why having 3 floppy drives would prevent system from booting from the HDD

mudmin, 2023-02-26:
Thanks for taking the time to respond. Gadget Reboot tried on the 286 in his video and got the same issue.

I tried on a 486 VLB motherboard with a SIS chipset and an award bios
A Socket 7 TL2 Motherboard with an Ami Bios
A Socket 7 TL3+  Motherboard with Ami Bios
with a Lo-tech XT-IDE XT ISA to IDE CompactFlash Adapter, an XT-IDE that I built myself and an IDE to SD solution on the stock controller.

All of the above appear to try to boot the 3rd floppy drive on the chain (regardless of first/second fdc location) instead of the hard drive.

I've spent all weekend fiddling with this. I'm open to using a different DOS image, but everything I've tried so far works great until I add that third drive and then that drive tries to boot.

skiselev, 2023-09-18:
In both cases, the problem seems to be the Universal XTIDE BIOS attempting to boot from the third floppy when drive "C" is selected. It is not related to the Monster FDC or Multi-floppy BIOS.
See the discussion at the [VCFed forum](https://forum.vcfed.org/index.php?threads/sergeys-8-bit-fdc-xt-ide.1242098/)

Closed 2023-09-18.

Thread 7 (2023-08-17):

Typo in Bill of Materials -- JP4 / JP5 are swapped

wrljet, 2023-08-17:
Sergey,

There appears to be a typo in the Bill of Materials, where JP4 and JP5 are swapped.

Bill

skiselev, 2023-09-18:
Fixed. Thanks for reporting!

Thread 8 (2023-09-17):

Typo in Assembly Instructions

wrljet, 2023-09-17:
Sergey,

While assembling my second copy of this board I noticed a minor typo in Assembly_Instructions.md:

```
and the negative (-) lead is shorted than the positive (+) one
```

`shorted` should be `shorter`

Bill

skiselev, 2023-09-18:
Typo fixed. Thank you for the feedback!

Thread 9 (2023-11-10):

Help diagnosing possible faulty controller

ImanolBarba, 2023-11-10:
So I built a couple of these boards, and they both seem to have the same issue:

- Floppy BIOS runs, so that much is fine
- As soon as the floppy cable is inserted into the card, irregardless of the card being powered or inserted anywhere, the floppy drive light comes on and stays on.
- OS detects floppies correctly as configured in the BIOS
- If I try to read from the drive it just does nothing and eventually the OS reports error
- I tried two different drives already, which I sourced from two different places

Could it be that the 82077aa controllers are bad or fake? I sourced all 4 of them from the same vendor.

I don't know how the controllers work, but it's weird the issue is present even when the card is not powered or grounded anywhere.

Any tips?

Thanks

skiselev, 2023-11-10:
Really two options:
1. Floppy interface cable is reversed. Please make sure that the cable is connected properly. Pin #1 is marked on the FDC board. It also should be marked on floppy drives. Floppy cables normally have the first wire colored red or purple
2. The FDC IC is bad. Did you use FDC ICs from a reliable supplier?

ImanolBarba, 2023-11-10:
Yeah my dumb ass was connecting the cable reversed on the drive, my bad.

Seems to work fine now, thanks for the help!

Closed 2023-11-10.

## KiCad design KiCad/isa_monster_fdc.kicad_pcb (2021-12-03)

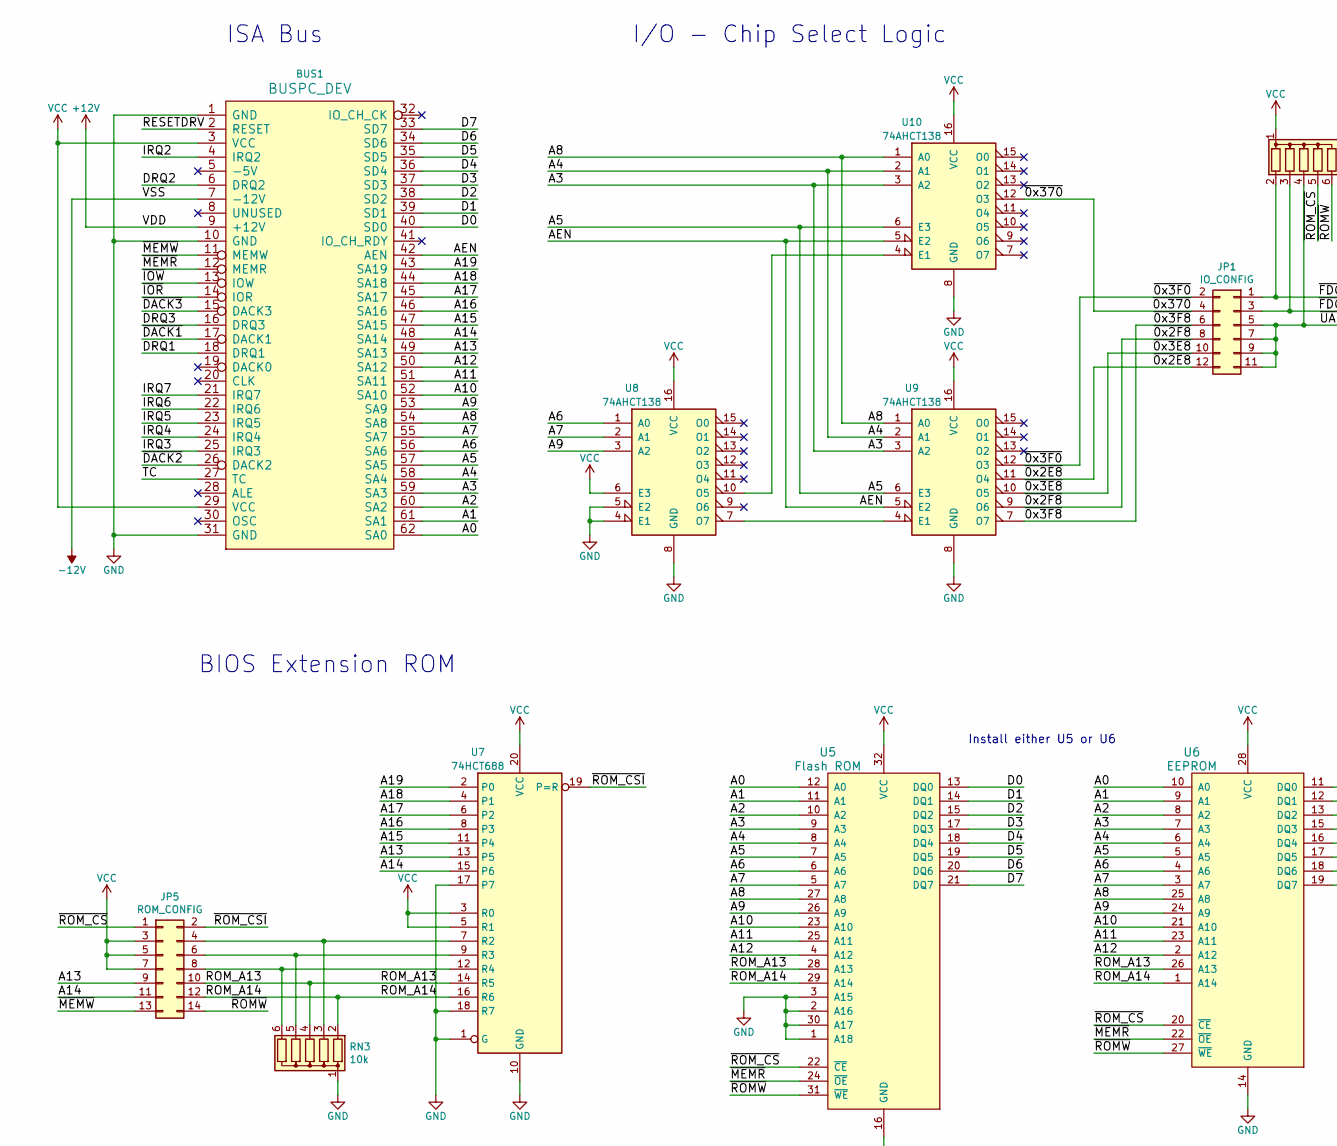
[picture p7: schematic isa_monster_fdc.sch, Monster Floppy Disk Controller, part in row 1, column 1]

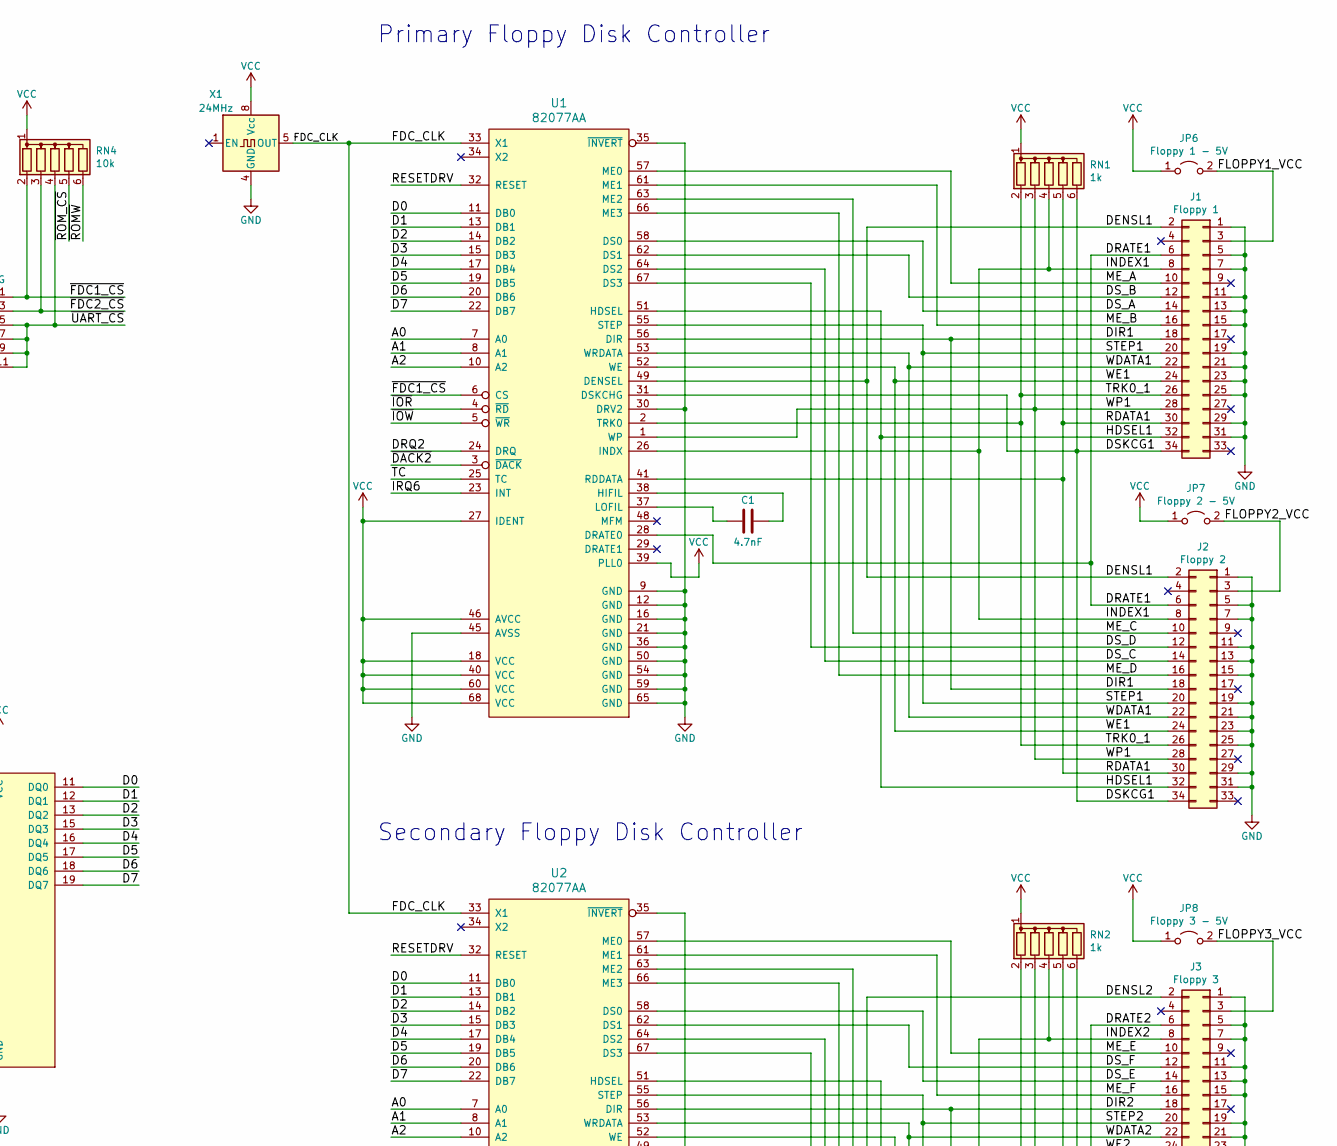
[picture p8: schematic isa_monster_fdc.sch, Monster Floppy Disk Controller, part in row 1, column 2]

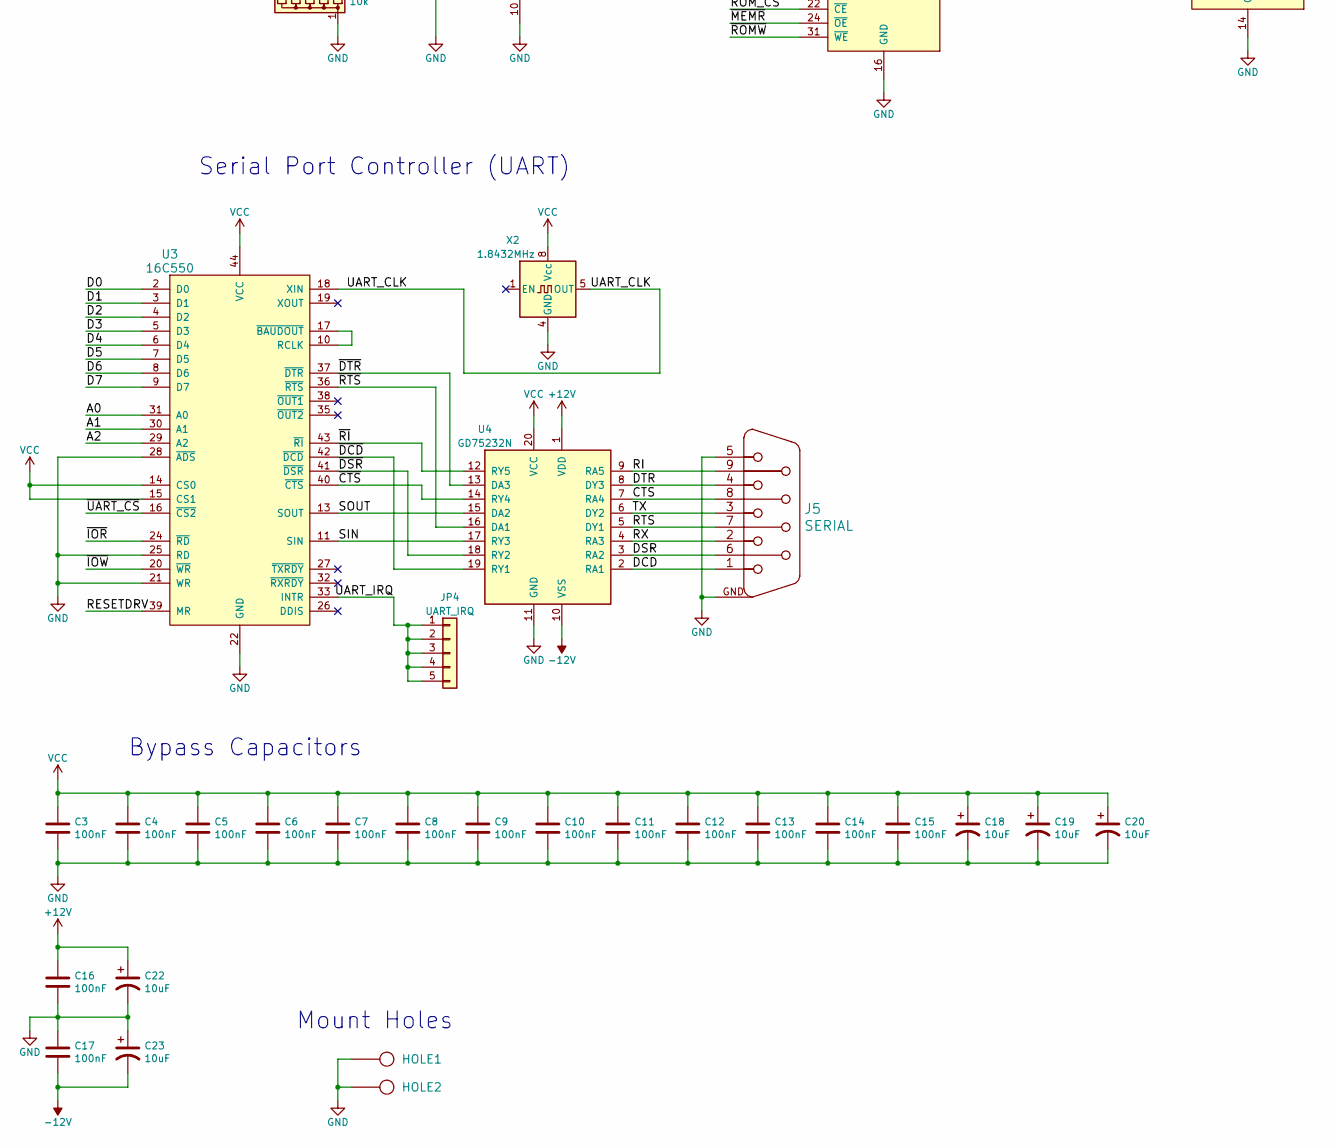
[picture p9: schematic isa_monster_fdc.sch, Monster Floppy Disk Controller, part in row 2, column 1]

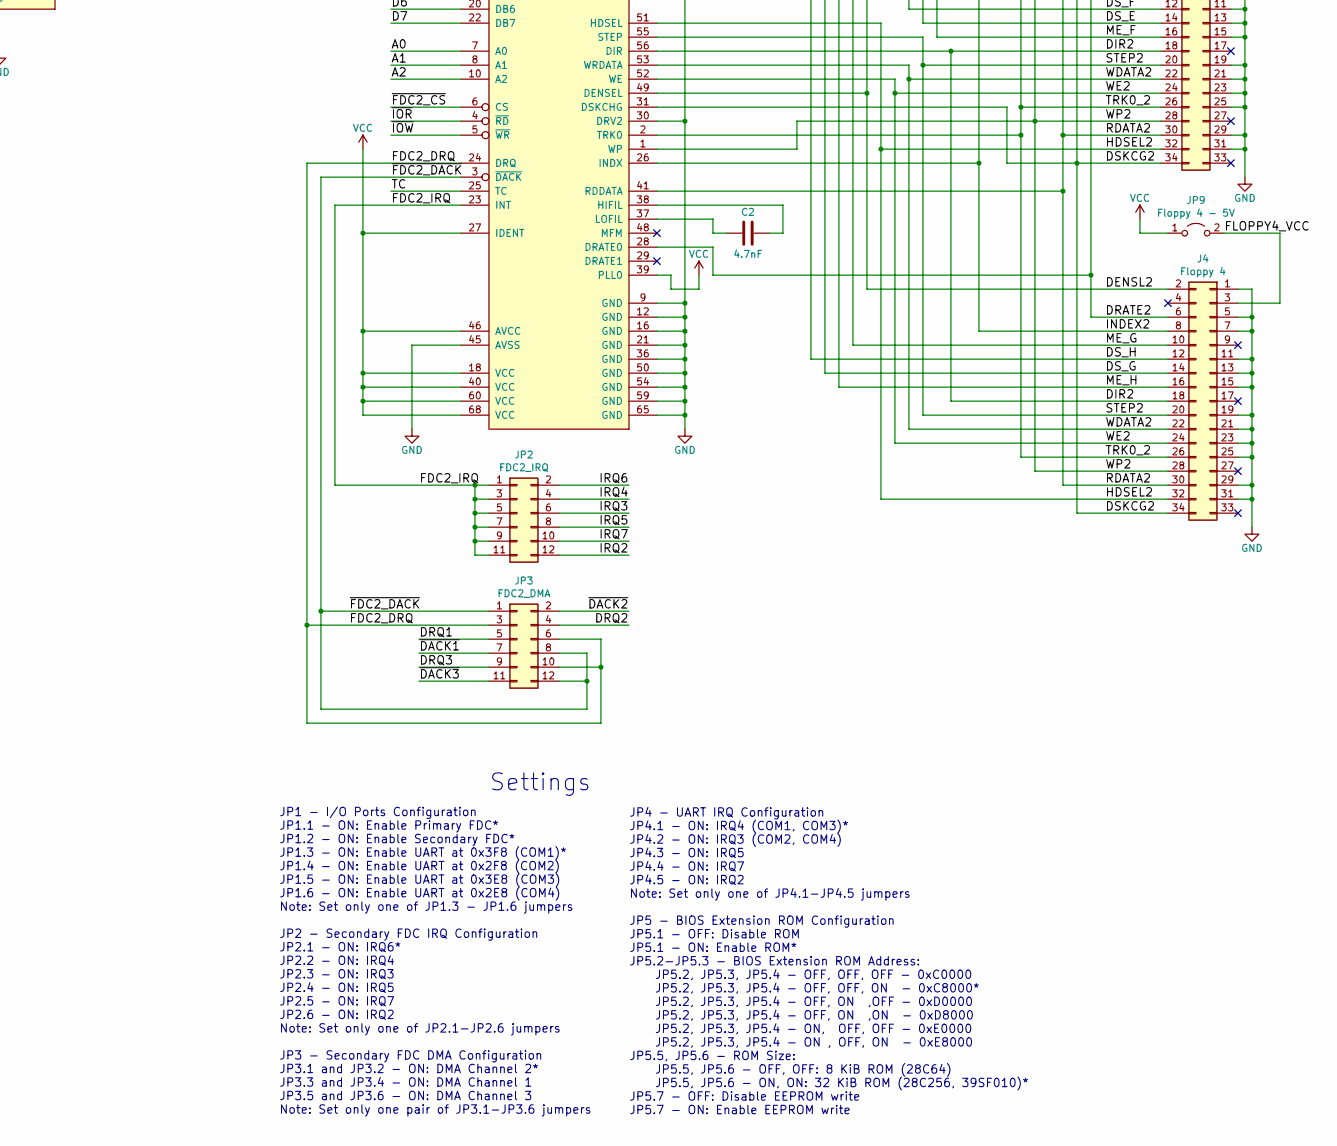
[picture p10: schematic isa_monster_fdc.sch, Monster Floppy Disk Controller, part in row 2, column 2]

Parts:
BUS1: BUSPC_DEV; Conn_Edge_PCB_ISA8
C1, C2: 4.7nF; Cap_Cer_508
C3, C4, C5, C6, C7, C8, C9, C10, C11, C12, C13, C14, C15, C16, C17: 100nF; Cap_Cer_508
C18, C19, C20, C22, C23: 10uF; Cap_Elec_Radial_6.3mm
HOLE1, HOLE2: HOLE; MountingHole_3.2mm_M3_Pad_Via
J1: Floppy 1; Conn_Pin_Header_17x2_2.54mm_Shrouded
J2: Floppy 2; Conn_Pin_Header_17x2_2.54mm_Shrouded
J3: Floppy 3; Conn_Pin_Header_17x2_2.54mm_Shrouded
J4: Floppy 4; Conn_Pin_Header_17x2_2.54mm_Shrouded
J5: SERIAL; Conn_Dsub_DE9M
JP1: IO_CONFIG; Conn_Pin_Header_6x2_2.54mm
JP2: FDC2_IRQ; Conn_Pin_Header_6x2_2.54mm
JP3: FDC2_DMA; Conn_Pin_Header_6x2_2.54mm
JP4: UART_IRQ; Conn_Pin_Header_5x1_2.54mm
JP5: ROM_CONFIG; Conn_Pin_Header_7x2_2.54mm
JP6: Floppy 1 - 5V; Conn_Pin_Header_2x1_2.54mm_NoKey
JP7: Floppy 2 - 5V; Conn_Pin_Header_2x1_2.54mm_NoKey
JP8: Floppy 3 - 5V; Conn_Pin_Header_2x1_2.54mm_NoKey
JP9: Floppy 4 - 5V; Conn_Pin_Header_2x1_2.54mm_NoKey
RN1, RN2: 1k; Conn_SIL6
RN3, RN4: 10k; Conn_SIL6
U1, U2: 82077AA; IC_PLCC68_TH
U3: 16C550; IC_PLCC44_TH
U4: GD75232N; IC_DIP20_300
U5: Flash ROM; IC_DIP32_600
U6: EEPROM; IC_DIP28_600
U7: 74HCT688; IC_DIP20_300
U8, U9, U10: 74AHCT138; IC_DIP16_300
X1: 24MHz; OSC_Half_Can_DIP8
X2: 1.8432MHz; OSC_Half_Can_DIP8

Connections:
+12V: BUS1.9 (+12V), C16.1, C22.1, U4.1 (VDD)
-12V: BUS1.7 (-12V), C17.2, C23.2, U4.10 (VSS)
/A0: BUS1.62 (SA0), U1.7 (A0), U2.7 (A0), U3.31 (A0), U5.12 (A0), U6.10 (A0)
/A1: BUS1.61 (SA1), U1.8 (A1), U2.8 (A1), U3.30 (A1), U5.11 (A1), U6.9 (A1)
/A2: BUS1.60 (SA2), U1.10 (A2), U2.10 (A2), U3.29 (A2), U5.10 (A2), U6.8 (A2)
/A3: BUS1.59 (SA3), U5.9 (A3), U6.7 (A3), U9.3 (A2), U10.3 (A2)
/A4: BUS1.58 (SA4), U5.8 (A4), U6.6 (A4), U9.2 (A1), U10.2 (A1)
/A5: BUS1.57 (SA5), U5.7 (A5), U6.5 (A5), U9.6 (E3), U10.6 (E3)
/A6: BUS1.56 (SA6), U5.6 (A6), U6.4 (A6), U8.1 (A0)
/A7: BUS1.55 (SA7), U5.5 (A7), U6.3 (A7), U8.2 (A1)
/A8: BUS1.54 (SA8), U5.27 (A8), U6.25 (A8), U9.1 (A0), U10.1 (A0)
/A9: BUS1.53 (SA9), U5.26 (A9), U6.24 (A9), U8.3 (A2)
/A10: BUS1.52 (SA10), U5.23 (A10), U6.21 (A10)
/A11: BUS1.51 (SA11), U5.25 (A11), U6.23 (A11)
/A12: BUS1.50 (SA12), U5.4 (A12), U6.2 (A12)
/A13: BUS1.49 (SA13), JP5.9, U7.13 (P5)
/A14: BUS1.48 (SA14), JP5.11, U7.15 (P6)
/A15: BUS1.47 (SA15), U7.11 (P4)
/A16: BUS1.46 (SA16), U7.8 (P3)
/A17: BUS1.45 (SA17), U7.6 (P2)
/A18: BUS1.44 (SA18), U7.4 (P1)
/A19: BUS1.43 (SA19), U7.2 (P0)
/AEN: BUS1.42 (AEN), U9.5 (E2), U10.5 (E2)
/CTS: J5.8, U4.7 (RA4)
/D0: BUS1.40 (SD0), U1.11 (DB0), U2.11 (DB0), U3.2 (D0), U5.13 (DQ0), U6.11 (DQ0)
/D1: BUS1.39 (SD1), U1.13 (DB1), U2.13 (DB1), U3.3 (D1), U5.14 (DQ1), U6.12 (DQ1)
/D2: BUS1.38 (SD2), U1.14 (DB2), U2.14 (DB2), U3.4 (D2), U5.15 (DQ2), U6.13 (DQ2)
/D3: BUS1.37 (SD3), U1.15 (DB3), U2.15 (DB3), U3.5 (D3), U5.17 (DQ3), U6.15 (DQ3)
/D4: BUS1.36 (SD4), U1.17 (DB4), U2.17 (DB4), U3.6 (D4), U5.18 (DQ4), U6.16 (DQ4)
/D5: BUS1.35 (SD5), U1.19 (DB5), U2.19 (DB5), U3.7 (D5), U5.19 (DQ5), U6.17 (DQ5)
/D6: BUS1.34 (SD6), U1.20 (DB6), U2.20 (DB6), U3.8 (D6), U5.20 (DQ6), U6.18 (DQ6)
/D7: BUS1.33 (SD7), U1.22 (DB7), U2.22 (DB7), U3.9 (D7), U5.21 (DQ7), U6.19 (DQ7)
/DCD: J5.1, U4.2 (RA1)
/DENSL1: J1.2, J2.2, U1.49 (DENSEL)
/DENSL2: J3.2, J4.2, U2.49 (DENSEL)
/DIR1: J1.18, J2.18, U1.56 (DIR)
/DIR2: J3.18, J4.18, U2.56 (DIR)
/DRATE1: J1.6, J2.6, U1.28 (DRATE0)
/DRATE2: J3.6, J4.6, U2.28 (DRATE0)
/DRQ1: BUS1.18 (DRQ1), JP3.5
/DRQ2: BUS1.6 (DRQ2), JP3.4, U1.24 (DRQ)
/DRQ3: BUS1.16 (DRQ3), JP3.9
/DSKCG1: J1.34, J2.34, RN1.6 (R5), U1.31 (DSKCHG)
/DSKCG2: J3.34, J4.34, RN2.6 (R5), U2.31 (DSKCHG)
/DSR: J5.6, U4.3 (RA2)
/DS_A: J1.14, U1.58 (DS0)
/DS_B: J1.12, U1.62 (DS1)
/DS_C: J2.14, U1.64 (DS2)
/DS_D: J2.12, U1.67 (DS3)
/DS_E: J3.14, U2.58 (DS0)
/DS_F: J3.12, U2.62 (DS1)
/DS_G: J4.14, U2.64 (DS2)
/DS_H: J4.12, U2.67 (DS3)
/DTR: J5.4, U4.8 (DY3)
/FDC2_DRQ: JP3.3, JP3.6, JP3.10, U2.24 (DRQ)
/FDC2_IRQ: JP2.1, JP2.3, JP2.5, JP2.7, JP2.9, JP2.11, U2.23 (INT)
/FDC_CLK: U1.33 (X1), U2.33 (X1), X1.5 (OUT)
/FLOPPY1_VCC: J1.3, JP6.2 (B)
/FLOPPY2_VCC: J2.3, JP7.2 (B)
/FLOPPY3_VCC: J3.3, JP8.2 (B)
/FLOPPY4_VCC: J4.3, JP9.2 (B)
/HDSEL1: J1.32, J2.32, U1.51 (HDSEL)
/HDSEL2: J3.32, J4.32, U2.51 (HDSEL)
/INDEX1: J1.8, J2.8, RN1.4 (R3), U1.26 (INDX)
/INDEX2: J3.8, J4.8, RN2.4 (R3), U2.26 (INDX)
/IRQ2: BUS1.4 (IRQ2), JP2.12
/IRQ3: BUS1.25 (IRQ3), JP2.6
/IRQ4: BUS1.24 (IRQ4), JP2.4
/IRQ5: BUS1.23 (IRQ5), JP2.8
/IRQ6: BUS1.22 (IRQ6), JP2.2, U1.23 (INT)
/IRQ7: BUS1.21 (IRQ7), JP2.10
/ME_A: J1.10, U1.57 (ME0)
/ME_B: J1.16, U1.61 (ME1)
/ME_C: J2.10, U1.63 (ME2)
/ME_D: J2.16, U1.66 (ME3)
/ME_E: J3.10, U2.57 (ME0)
/ME_F: J3.16, U2.61 (ME1)
/ME_G: J4.10, U2.63 (ME2)
/ME_H: J4.16, U2.66 (ME3)
/RDATA1: J1.30, J2.30, RN1.5 (R4), U1.41 (RDDATA)
/RDATA2: J3.30, J4.30, RN2.5 (R4), U2.41 (RDDATA)
/RESETDRV: BUS1.2 (RESET), U1.32 (RESET), U2.32 (RESET), U3.39 (MR)
/RI: J5.9, U4.9 (RA5)
/ROM_A13: JP5.10, RN3.4 (R3), U5.28 (A13), U6.26 (A13), U7.14 (R5)
/ROM_A14: JP5.12, RN3.2 (R1), U5.29 (A14), U6.1 (A14), U7.16 (R6)
/RTS: J5.7, U4.5 (DY1)
/RX: J5.2, U4.4 (RA3)
/SIN: U3.11 (SIN), U4.17 (RY3)
/SOUT: U3.13 (SOUT), U4.15 (DA2)
/STEP1: J1.20, J2.20, U1.55 (STEP)
/STEP2: J3.20, J4.20, U2.55 (STEP)
/TC: BUS1.27 (TC), U1.25 (TC), U2.25 (TC)
/TRK0_1: J1.26, J2.26, RN1.2 (R1), U1.2 (TRK0)
/TRK0_2: J3.26, J4.26, RN2.2 (R1), U2.2 (TRK0)
/TX: J5.3, U4.6 (DY2)
/UART_CLK: U3.18 (XIN), X2.5 (OUT)
/UART_IRQ: JP4.1, JP4.2, JP4.3, JP4.4, JP4.5, U3.33 (INTR)
/WDATA1: J1.22, J2.22, U1.53 (WRDATA)
/WDATA2: J3.22, J4.22, U2.53 (WRDATA)
/WE1: J1.24, J2.24, U1.52 (WE)
/WE2: J3.24, J4.24, U2.52 (WE)
/WP1: J1.28, J2.28, RN1.3 (R2), U1.1 (WP)
/WP2: J3.28, J4.28, RN2.3 (R2), U2.1 (WP)
/~0x2E8: JP1.12, U9.11 (O4)
/~0x2F8: JP1.8, U9.9 (O6)
/~0x3E8: JP1.10, U9.10 (O5)
/~0x3F0: JP1.2, U9.12 (O3)
/~0x3F8: JP1.6, U9.7 (O7)
/~0x370: JP1.4, U10.12 (O3)
/~CTS: U3.40 (~CTS), U4.14 (RY4)
/~DACK1: BUS1.17 (DACK1), JP3.7
/~DACK2: BUS1.26 (DACK2), JP3.2, U1.3 (~DACK)
/~DACK3: BUS1.15 (DACK3), JP3.11
/~DCD: U3.42 (~DCD), U4.19 (RY1)
/~DSR: U3.41 (~DSR), U4.18 (RY2)
/~DTR: U3.37 (~DTR), U4.13 (DA3)
/~FDC1_CS: JP1.1, RN4.2 (R1), U1.6 (CS)
/~FDC2_CS: JP1.3, RN4.3 (R2), U2.6 (CS)
/~FDC2_DACK: JP3.1, JP3.8, JP3.12, U2.3 (~DACK)
/~IOR: BUS1.14 (IOR), U1.4 (~RD), U2.4 (~RD), U3.24 (~RD)
/~IOW: BUS1.13 (IOW), U1.5 (~WR), U2.5 (~WR), U3.20 (~WR)
/~MEMR: BUS1.12 (MEMR), U5.24 (~OE), U6.22 (~OE)
/~MEMW: BUS1.11 (MEMW), JP5.13
/~RI: U3.43 (~RI), U4.12 (RY5)
/~ROMW: JP5.14, RN4.6 (R5), U5.31 (~WE), U6.27 (~WE)
/~ROM_CS: JP5.1, RN4.5 (R4), U5.22 (~CE), U6.20 (~CE)
/~ROM_CSI: JP5.2, U7.19 (P=R)
/~RTS: U3.36 (~RTS), U4.16 (DA1)
/~UART_CS: JP1.5, JP1.7, JP1.9, JP1.11, RN4.4 (R3), U3.16 (~CS2)
GND: BUS1.1 (GND), BUS1.10 (GND), BUS1.31 (GND), C3.2, C4.2, C5.2, C6.2, C7.2, C8.2, C9.2, C10.2, C11.2, C12.2, C13.2, C14.2, C15.2, C16.2, C17.1, C18.2, C19.2, C20.2, C22.2, C23.1, HOLE1.1, HOLE2.1, J1.1, J1.5, J1.7, J1.11, J1.13, J1.15, J1.19, J1.21, J1.23, J1.25, J1.29, J1.31, J2.1, J2.5, J2.7, J2.11, J2.13, J2.15, J2.19, J2.21, J2.23, J2.25, J2.29, J2.31, J3.1, J3.5, J3.7, J3.11, J3.13, J3.15, J3.19, J3.21, J3.23, J3.25, J3.29, J3.31, J4.1, J4.5, J4.7, J4.11, J4.13, J4.15, J4.19, J4.21, J4.23, J4.25, J4.29, J4.31, J5.5, J5.GND, RN3.1 (common), U1.9 (GND), U1.12 (GND), U1.16 (GND), U1.21 (GND), U1.30 (DRV2), U1.35 (~INVERT), U1.36 (GND), U1.45 (AVSS), U1.50 (GND), U1.54 (GND), U1.59 (GND), U1.65 (GND), U2.9 (GND), U2.12 (GND), U2.16 (GND), U2.21 (GND), U2.30 (DRV2), U2.35 (~INVERT), U2.36 (GND), U2.45 (AVSS), U2.50 (GND), U2.54 (GND), U2.59 (GND), U2.65 (GND), U3.21 (WR), U3.22 (GND), U3.25 (RD), U3.28 (~ADS), U4.11 (GND), U5.1 (A18), U5.2 (A16), U5.3 (A15), U5.16 (GND), U5.30 (A17), U6.14 (GND), U7.1 (G), U7.10 (GND), U7.17 (P7), U7.18 (R7), U8.4 (E1), U8.5 (E2), U8.8 (GND), U9.8 (GND), U10.8 (GND), X1.4 (GND), X2.4 (GND)
unnamed: C1.1, U1.38 (HIFIL)
unnamed: C1.2, U1.37 (LOFIL)
unnamed: C2.1, U2.38 (HIFIL)
unnamed: C2.2, U2.37 (LOFIL)
unnamed: JP5.4, RN3.3 (R2), U7.7 (R2)
unnamed: JP5.6, RN3.5 (R4), U7.9 (R3)
unnamed: JP5.8, RN3.6 (R5), U7.12 (R4)
unnamed: U3.10 (RCLK), U3.17 (~BAUDOUT)
unnamed: U8.7 (O7), U9.4 (E1)
unnamed: U8.10 (O5), U10.4 (E1)
VCC: BUS1.3 (VCC), BUS1.29 (VCC), C3.1, C4.1, C5.1, C6.1, C7.1, C8.1, C9.1, C10.1, C11.1, C12.1, C13.1, C14.1, C15.1, C18.1, C19.1, C20.1, JP5.3, JP5.5, JP5.7, JP6.1 (A), JP7.1 (A), JP8.1 (A), JP9.1 (A), RN1.1 (common), RN2.1 (common), RN4.1 (common), U1.18 (VCC), U1.27 (IDENT), U1.39 (PLL0), U1.40 (VCC), U1.46 (AVCC), U1.60 (VCC), U1.68 (VCC), U2.18 (VCC), U2.27 (IDENT), U2.39 (PLL0), U2.40 (VCC), U2.46 (AVCC), U2.60 (VCC), U2.68 (VCC), U3.14 (CS0), U3.15 (CS1), U3.44 (VCC), U4.20 (VCC), U5.32 (VCC), U6.28 (VCC), U7.3 (R0), U7.5 (R1), U7.20 (VCC), U8.6 (E3), U8.16 (VCC), U9.16 (VCC), U10.16 (VCC), X1.8 (Vcc), X2.8 (Vcc)

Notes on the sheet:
ISA Bus
BIOS Extension ROM
Bypass Capacitors
Mount Holes
I/O - Chip Select Logic
Serial Port Controller (UART)
Primary Floppy Disk Controller
Settings
Secondary Floppy Disk Controller
Install either U5 or U6
JP4 - UART IRQ Configuration JP4.1 - ON: IRQ4 (COM1, COM3)* JP4.2 - ON: IRQ3 (COM2, COM4) JP4.3 - ON: IRQ5 JP4.4 - ON: IRQ7 JP4.5 - ON: IRQ2 Note: Set only one of JP4.1-JP4.5 jumpers JP5 - BIOS Extension ROM Configuration JP5.1 - OFF: Disable ROM JP5.1 - ON: Enable ROM* JP5.2-JP5.3 - BIOS Extension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
JP1 - I/O Ports Configuration JP1.1 - ON: Enable Primary FDC* JP1.2 - ON: Enable Secondary FDC* JP1.3 - ON: Enable UART at 0x3F8 (COM1)* JP1.4 - ON: Enable UART at 0x2F8 (COM2) JP1.5 - ON: Enable UART at 0x3E8 (COM3) JP1.6 - ON: Enable UART at 0x2E8 (COM4) Note: Set only one of JP1.3 - JP1.6 jumper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

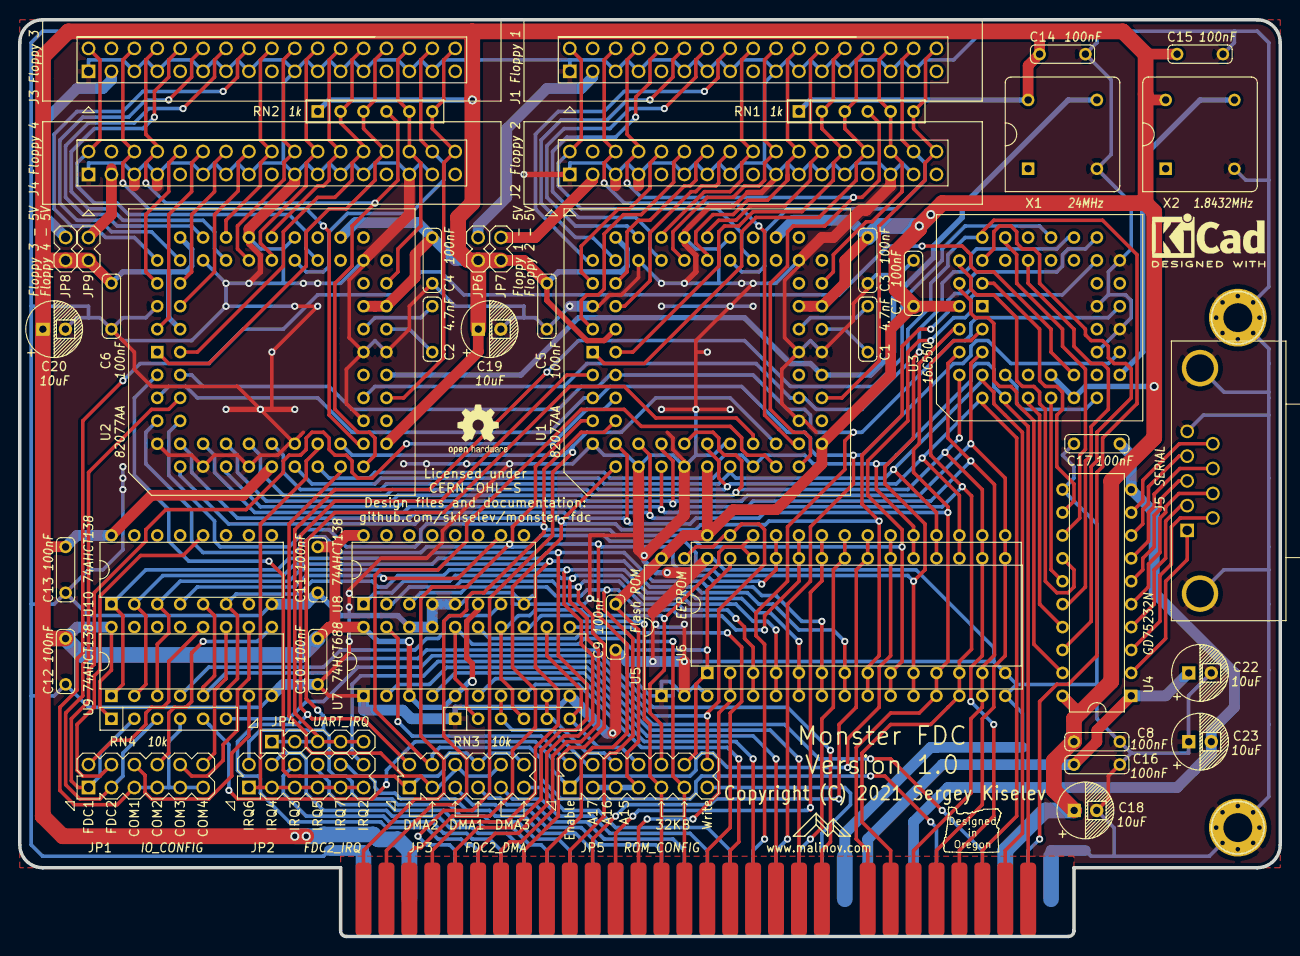
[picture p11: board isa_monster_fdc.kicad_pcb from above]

Board: 2 copper layers, 139.7 x 101.6 mm, 55 parts (0 on the bottom side), 141 nets.

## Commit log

2021-12-03 Add files for version 1.0
    [isa_monster_fdc-B_Mask.gbs, isa_monster_fdc-B_SilkS.gbo, isa_monster_fdc-Back.gbl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]
2021-12-03 Update board rendering
2021-12-03 README: Board rendering, board and schematic links
2022-01-24 Add photos of the actual board
2023-09-18 Assembly_Instructions.md: Fix a typo
2023-09-18 README.md: Fix an error in the BOM: swap JP4 and JP5
2024-02-07 Add link to a 3D printed bracket

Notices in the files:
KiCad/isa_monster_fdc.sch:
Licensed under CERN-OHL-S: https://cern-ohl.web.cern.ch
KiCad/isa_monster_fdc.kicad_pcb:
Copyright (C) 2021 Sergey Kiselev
